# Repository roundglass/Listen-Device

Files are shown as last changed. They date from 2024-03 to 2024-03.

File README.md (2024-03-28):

# Roundglass Sustain Listen : Realtime Acoustic

## Monitoring

- **_Listen_**  is a modular acoustic station (device) and software / program to analyze sounds
- **_Listen_** is an end-end solution to collect sounds on the ground to infer intelligence
- **_Listen_** differs from other acoustic stations available in the market in its ease-of-use,
    set-up and portability
- It relies on solar-power, long-lasting battery and a plug-n-play communication system
    that would transmit data real-time to a console or App or Web interface.
- The data will be available real-time on smartphone/tablet through an application and
    would enable users to make informed decisions. Potential users are conservation and
    law enforcement personnel (forest department primarily) and NGOs and local
    communities who are interested in conserving their natural heritage.
- The app has capabilities to view data as graphs and in other forms of visualization. (Ex:
    used to observe trend of data over a requested time period like the sound
    characteristics.

## How does  Listen  work?

### Listen: working illustration

Listen isolates ‘sounds-of-interest’ from the surrounding or ambient sound. Sounds-of-interest
can be defined according to our needs - gunshots, dynamite blasts, motor vehicles, timber
felling, etc. The unit(Listen Mote) is installed in field and designed to blend in with the
surroundings - hidden in the tree canopy, etc. This can stay deployed for at least 4 weeks
without a battery change. There exists an option to connect it to a solar charger for longer
deployments. 

High-sensitivity microphones coupled with a data transmission system form the
field unit (Listen Mote). Information is received at a base station over cellular network.
The audio recording based on the programmed recording frequency is uploaded to our cloud
database which is linked to our cloud based virtual analytics system, once the system
determines that a particular recording is of interest (anomaly in the environment) then an alert is
sent out to the respective authority.

We foresee a need for these devices in the coming years owing to increased awareness
regarding conservation issues and also due to severe shortage of enforcement and patrol
personnel guarding our protected areas.

## Hardware 

### Roundglass Sustain Listen: components

**Microphones** : A high sensitivity microphone is used that will work for far field listening and has
digital gain to isolate noise amplification as in analog signal amplification.

**Form factor:**  Easy to conceal, hard shell polycarbonate, rounded edges, matte finish, no
external wiring or protruding antenna.

**Power source:** Solar powered with alternate power input for seasons and places with no
adequate solar radiation.

**Battery** : Li-ion pack can stay powered and deployed in field for at least 4 weeks without charge.

**Communication** : Wireless (GSM)

**Data** : App and Web based monitoring, configurable frequency and format of logging and
transmission.

**Switches** : Waterproof, dust-proof and insect-proof. No external switches.

**Mounting** : Compact system can be mounted on a mast or tripod of your choice.

## Technical Specifications

**Communication** : Global GSM

**Temperature** : -20 to 60 C

**Weatherproof** : IP 66/

**Battery:**  Rechargeable Li-ion battery.

**Solar Panel:**  Optional

**Alternate Power source** : Can plug a 6-12V external DC power supply (Optional)

**Application:** Android and iOS

## Applications

Protected areas are often vast, remote, with difficult terrain and severely understaffed to
effectively monitor and protect. With Roundglass Sustain Listen, we hope to plug in some of these gaps to
effectively monitor large areas and identify threats.

1. Detection of gunshots in protected areas - poaching and hunting increasingly rely on
    guns and is one of the leading causes of wildlife decline
2. Detection of dynamite fishing along rivers - illegal and highly destructive. The
    conservation and livelihood impacts of dynamite fishing is enormous
3. Detection of vehicular movement in protected areas - motor vehicles are used to illegally
    access areas for poaching, hunting and timber smuggling.
4. Another potential application (which we hope to address at a later date) is detection of
    wildfires

## Highlights:

1. Detects, locates and alerts on threat sounds in less than 60 seconds.

2. Simple, affordable subscription service — no IT integration required

3. Get notified on your existing mobile phone via SMS / App notification.

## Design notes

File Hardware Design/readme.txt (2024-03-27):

#Hardware Design

Schematics and PCB Design

Platform Eagle

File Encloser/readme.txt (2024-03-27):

#Encloser

STL and G code

Platform: Fusion 360 for Designing
	  PrusaSlicer for G Code

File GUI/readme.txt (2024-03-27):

#GUI

GUI V0.4

Steps to convert .py to .exe

1. Open cmd window and type 'pip install pyinstaller'
2. Open where python File is located in our case go inside Source folder
3. Press Shift and Right click at the Same location.
4. Click on ‘Open PowerShell window here’. 
5. Now type pyinstaller --listenConfig -w 'ListenConfig.py'

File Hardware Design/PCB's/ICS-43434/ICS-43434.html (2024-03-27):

Partlist exported from C:/Users/AdityaGarg/OneDrive - RoundGlass/Documents/EAGLE/projects/ICS-43434/ICS-43434.sch at 8/22/2023 10:27 AM

Part | Value | Device | Package | Description
C1 | 100nf | CC0805KRX7R9BB104 | CAP_0805 | CAP CER 0.1UF 50V X7R 0805
GND | | PINHD-1X1CB | 1X01-CLEANBIG | Pin header 1x1 for 0.1" spacing
IC1 | ICS-43434 | ICS-43434 | ICS43434 | MEMS Microphones (Microphone), SNR(Nom)=65dBA, LxWxT (mm)=3.5x2.65x0.98
LR | | PINHD-1X1CB | 1X01-CLEANBIG | Pin header 1x1 for 0.1" spacing
R1 | 100k | R-US_R0805 | R0805 | RESISTOR, American symbol
SCK | | PINHD-1X1CB | 1X01-CLEANBIG | Pin header 1x1 for 0.1" spacing
SD | | PINHD-1X1CB | 1X01-CLEANBIG | Pin header 1x1 for 0.1" spacing
VDD | | PINHD-1X1CB | 1X01-CLEANBIG | Pin header 1x1 for 0.1" spacing
WS | | PINHD-1X1CB | 1X01-CLEANBIG | Pin header 1x1 for 0.1" spacing

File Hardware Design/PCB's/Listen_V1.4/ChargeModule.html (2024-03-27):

Partlist exported from C:/Users/AdityaGarg/OneDrive - RoundGlass/Documents/EAGLE/projects/Listen_V1.4/ChargeModule.sch at 9/4/2023 12:24 PM

Qty | Value | Device | Package | Parts | Description | AVAILABILITY | DESCRIPTION | MARK | MF | MP | MPN | PACKAGE | POPULARITY | PRICE | PROD_ID | PURCHASE-URL | SPICEPREFIX
2 | | PINHD-1X6JSTXH | JST-XH-06-PACKAGE-ROUND-PAD | JP1, JP2 | PIN HEADER
1 | | USB_MICRO-B_FEMALE-SMT | USB-B-MICRO-SMD | J1 | USB Type Micro-B Connector | | | | | | | | | | CONN-11752
1 | 0 | R-US_M0805 | M0805 | R5 | RESISTOR, American symbol
1 | 0.1uf | RC-MASTER-SMD_C_0805MP | RC-MASTER-SMD_C0805MP | C7 | NON-POLARIZED CAP
1 | 1.0uH | L-USWE-TPC | POWER-CHOKE_WE-TPC | L1 | INDUCTOR, American symbol | | | | | | | | 0 | | | | L
1 | 100 | R-EU_R0805 | R0805 | R42 | RESISTOR, European symbol
1 | 100k | R-US_M0805 | M0805 | R3 | RESISTOR, American symbol
2 | 10k | R-US_M0805 | M0805 | R6, R7 | RESISTOR, American symbol
3 | 10uF | RC-MASTER-SMD_C_0805MP | RC-MASTER-SMD_C0805MP | C2, C3, C8 | NON-POLARIZED CAP
1 | 1K | R-EU_R0805 | R0805 | R43 | RESISTOR, European symbol
1 | 1k | R-US_M0805 | M0805 | R2 | RESISTOR, American symbol
1 | 1uF | RC-MASTER-SMD_C_0805MP | RC-MASTER-SMD_C0805MP | C1 | NON-POLARIZED CAP
2 | 22uF | RC-MASTER-SMD_C_0805MP | RC-MASTER-SMD_C0805MP | C5, C6 | NON-POLARIZED CAP
1 | 2k | R-US_M0805 | M0805 | R1 | RESISTOR, American symbol
1 | 47nF | RC-MASTER-SMD_C_0805MP | RC-MASTER-SMD_C0805MP | C4 | NON-POLARIZED CAP
2 | BK-18650-PC4 | BK-18650-PC4 | BAT_BK-18650-PC4 | BT1, BT2 | Battery Holder (Open) 18650 2 Cell PC Pin Check availability | In Stock | Battery Holder (Open) 18650 2 Cell PC Pin | | MPD | BK-18650-PC4 | | None | | None | | https://pricing.snapeda.com/search/part/BK-18650-PC4/?ref=eda
1 | DW01A | DW01A | SOT23-6 | IC3 | Check availability | Not in stock | One Cell Lithium-ion/Polymer Battery Protection IC | | Fortune Semiconductor | DW01A | | SOT-23-6 Fortune Semiconductor | | None
1 | FS8205 | FS8205 | SOT95P280X145-6N | Q2 | Dual N Channel Enhancement Mode Power MOSFET Check availability | Not in stock | Dual N-Channel Enhancement Mode Power MOSFET | | Fortune Semiconductor | FS8205 | | Package | | None
2 | JST-XH-02-PIN-ROUND-PAD | JST-XH-02-PIN-ROUND-PAD | JST-XH-02-PACKAGE-ROUND-PAD | X1, X2 | JST XH Connector 2 Pin
1 | MP2731GQC | MP2731GQC | QFN-26-3.5 | IC1 | | | | BMA__ | Monolithic Power | | MP2731GQC-0000-Z

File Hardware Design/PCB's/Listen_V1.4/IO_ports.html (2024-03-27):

Partlist exported from C:/Users/AdityaGarg/OneDrive - RoundGlass/Documents/EAGLE/projects/Listen_V1.4/IO_ports.sch at 8/22/2023 10:24 AM

Part | Value | Device | Package | Description
J6 | USB3131-30-0230-A | USB3131-30-0230-A | USB3131300230A | GCT (GLOBAL CONNECTOR TECHNOLOGY) - USB3131-30-0230-A - MICRO USB, 2.0 TYPE B, RECEPTACLE, THT
JP1 | | PINHD-1X6JSTXH | JST-XH-06-PACKAGE-ROUND-PAD | PIN HEADER
JP2 | | PINHD-1X6JSTXH | JST-XH-06-PACKAGE-ROUND-PAD | PIN HEADER
LED1 | | LEDCHIP-LED0805 | CHIP-LED0805 | LED
LED2 | | LEDCHIP-LED0805 | CHIP-LED0805 | LED
R1 | 2k | R-US_M0805 | M0805 | RESISTOR, American symbol
R4 | 2k | R-US_M0805 | M0805 | RESISTOR, American symbol
R7 | 1k | R-US_CHIP-0805(2012-METRIC) | RESC2012X65 | Resistor Fixed - ANSI
S1 | switch | MOMENTARY-SWITCH-SPST-PTH-6.0MM | TACTILE_SWITCH_PTH_6.0MM | Momentary Switch (Pushbutton) - SPST
S2 | Power Switch | MSS-102545-28A-D | SW_MSS-102545-28A-D | Check availability
X1 | JST-XH-02-PIN-LONG-PAD | JST-XH-02-PIN-LONG-PAD | JST-XH-02-PACKAGE-LONG-PAD | JST XH Connector 2 Pin
X2 | JST-XH-02-PIN-LONG-PAD | JST-XH-02-PIN-LONG-PAD | JST-XH-02-PACKAGE-LONG-PAD | JST XH Connector 2 Pin
X3 | JST-XH-03-PIN-LONG-PAD | JST-XH-03-PIN-LONG-PAD | JST-XH-03-PACKAGE-LONG-PAD | JST XH Connector 2 Pin
X4 | JST-XH-03-PIN-LONG-PAD | JST-XH-03-PIN-LONG-PAD | JST-XH-03-PACKAGE-LONG-PAD | JST XH Connector 2 Pin

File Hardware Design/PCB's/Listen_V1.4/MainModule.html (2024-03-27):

Partlist exported from C:/Users/AdityaGarg/OneDrive - RoundGlass/Documents/EAGLE/projects/Listen_V1.4/MainModule.sch at 8/22/2023 10:25 AM

Part | Value | Device | Package | Description
BME280 | | PINHD-1X6JSTXH | JST-XH-06-PACKAGE-ROUND-PAD | PIN HEADER
LEFT | | PINHD-1X6JSTXH | JST-XH-06-PACKAGE-ROUND-PAD | PIN HEADER
MODEM | | PINHD-1X6JSTXH | JST-XH-06-PACKAGE-ROUND-PAD | PIN HEADER
POWER | | PINHD-1X6JSTXH | JST-XH-06-PACKAGE-ROUND-PAD | PIN HEADER
R1 | 22k | R-US_CHIP-0805(2012-METRIC) | RESC2012X65 | Resistor Fixed - ANSI
R2 | 22k | R-US_CHIP-0805(2012-METRIC) | RESC2012X65 | Resistor Fixed - ANSI
RIGHT | | PINHD-1X6JSTXH | JST-XH-06-PACKAGE-ROUND-PAD | PIN HEADER
U$1 | 4GMODULE4GMODULE | 4GMODULE4GMODULE | 4GMODULE
U$2 | GPSANTENA | GPSANTENA | GPSANTENA
U1 | DEV-16771 | DEV-16771 | MODULE_DEV-16771 | RT1062 Teensy 4.1 i.MX ARM Cortex-M7 MPU Embedded Evaluation Board Check availability
U2 | 1053 | 1053 | 1053 | Coin Cell Battery Holders BATTERY HOLDER FOR CR2450
X1 | SOIL | JST-XH-02-PIN-LONG-PAD | JST-XH-02-PACKAGE-LONG-PAD | JST XH Connector 2 Pin

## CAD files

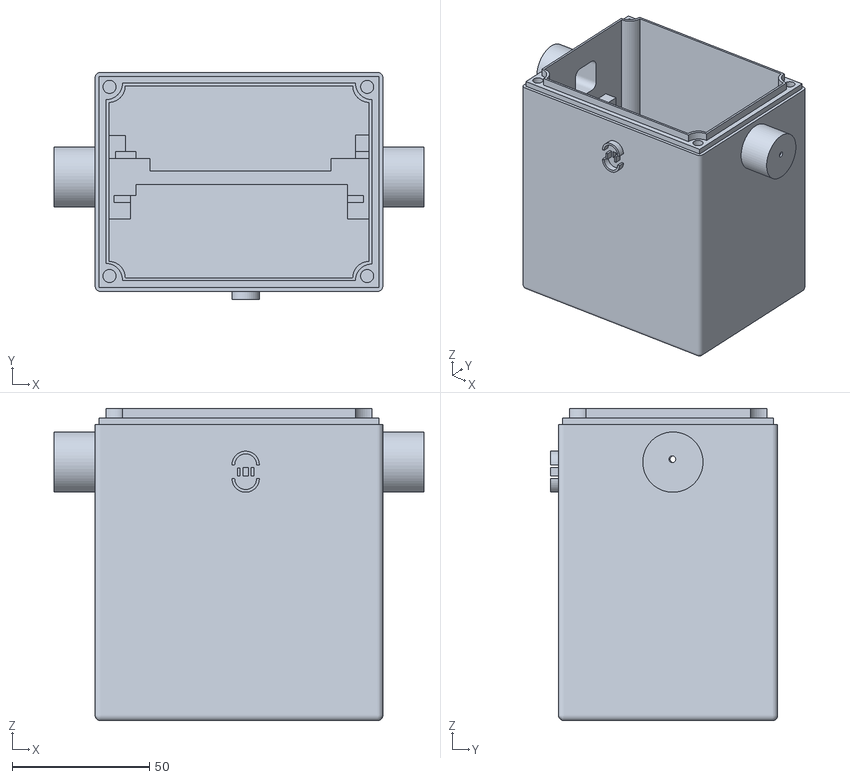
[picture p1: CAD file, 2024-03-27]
Encloser/STL/Encloser ListenV1.4 Base (In MIC).stl
135.0 x 83.0 x 114.0

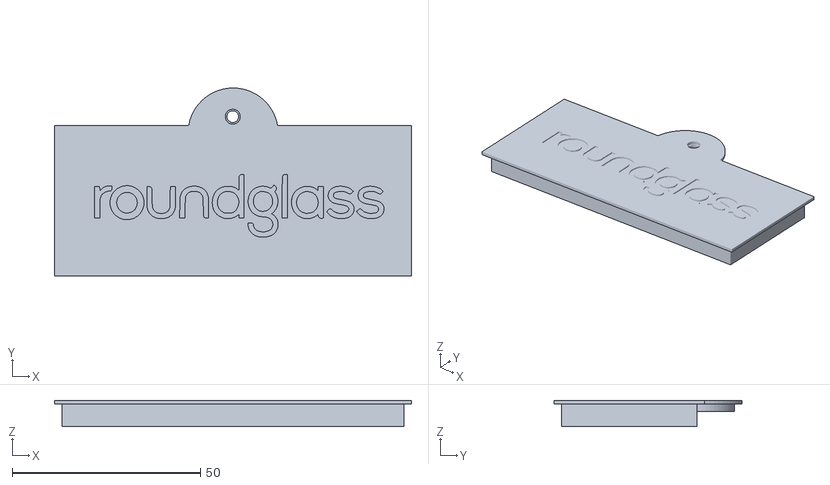
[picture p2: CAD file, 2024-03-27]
Encloser/STL/Encloser ListenV1.4 IOPort.stl
94.9 x 50.0 x 7.00

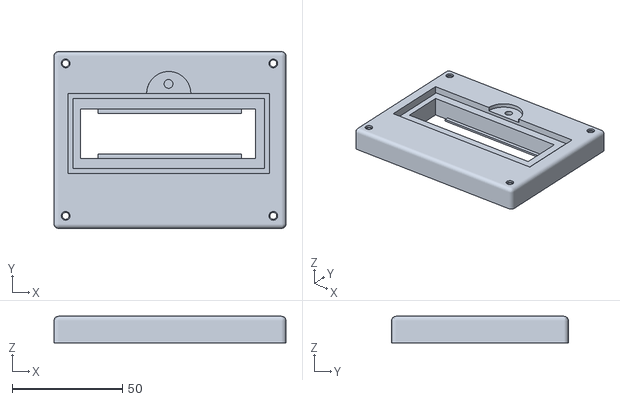
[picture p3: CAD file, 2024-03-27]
Encloser/STL/Encloser ListenV1.4 TOP.stl
105.0 x 80.0 x 12.0

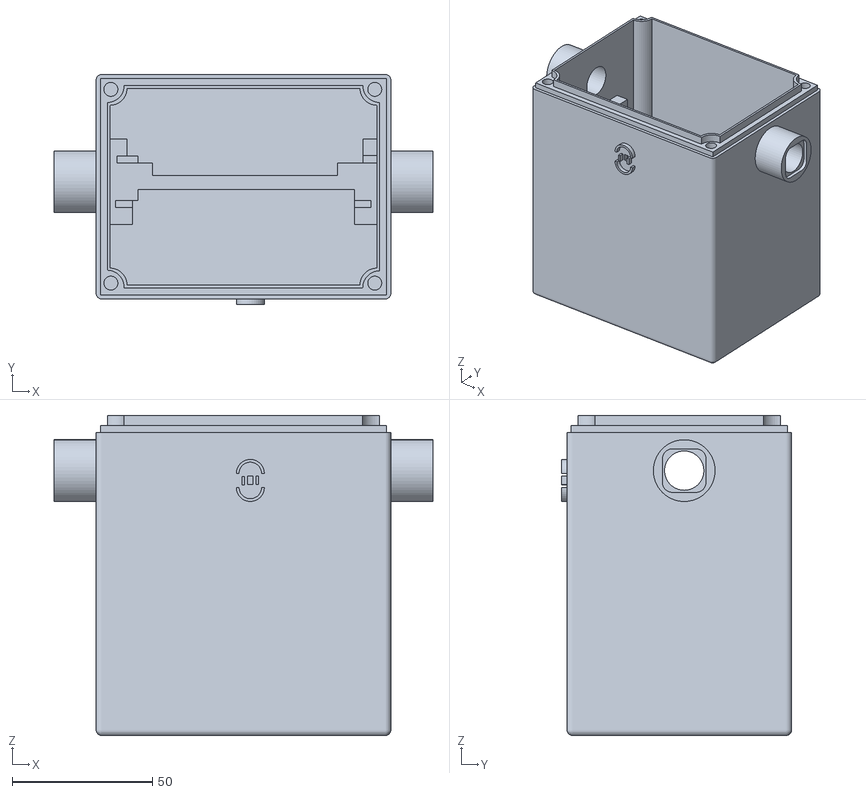
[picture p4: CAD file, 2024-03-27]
Encloser/STL/Encloser ListenV1.4 Base.stl
135.0 x 82.0 x 114.0

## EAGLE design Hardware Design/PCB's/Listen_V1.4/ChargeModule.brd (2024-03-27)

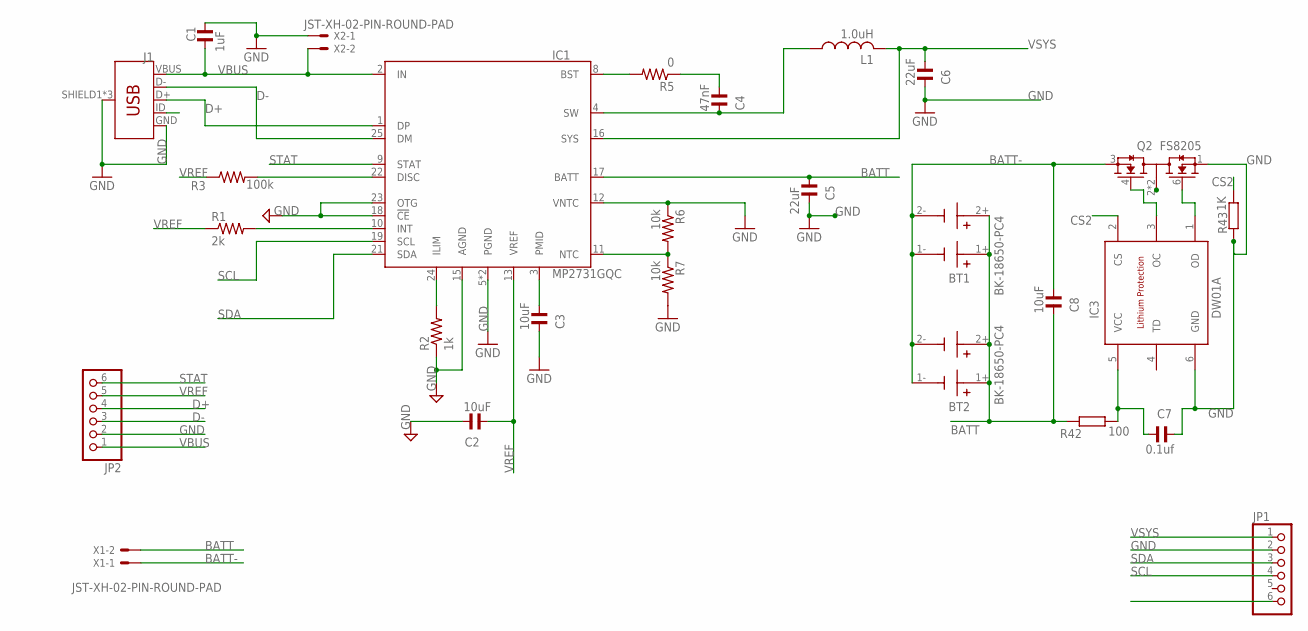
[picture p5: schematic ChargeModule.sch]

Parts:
BT1, BT2: BK-18650-PC4; BAT_BK-18650-PC4
C1: 1uF; RC-MASTER-SMD_C0805MP
C2, C3, C8: 10uF; RC-MASTER-SMD_C0805MP
C4: 47nF; RC-MASTER-SMD_C0805MP
C5, C6: 22uF; RC-MASTER-SMD_C0805MP
C7: 0.1uf; RC-MASTER-SMD_C0805MP
IC1: MP2731GQC; QFN-26-3.5
IC3: DW01A; SOT23-6
J1: USB_MICRO-B_FEMALE-SMT; USB-B-MICRO-SMD
JP1, JP2: PINHD-1X6JSTXH; JST-XH-06-PACKAGE-ROUND-PAD
L1: 1.0uH; POWER-CHOKE_WE-TPC
Q2: FS8205; SOT95P280X145-6N
R1: 2k; M0805
R2: 1k; M0805
R3: 100k; M0805
R5: 0; M0805
R6, R7: 10k; M0805
R42: 100; R0805
R43: 1K; R0805
X1, X2: JST-XH-02-PIN-ROUND-PAD; JST-XH-02-PACKAGE-ROUND-PAD

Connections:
BATT: BT1.1+, BT1.2+, BT2.1+, BT2.2+, C5.1, C8.2, IC1.17 (BATT), R42.2, X1.2
BATT-: BT1.1-, BT1.2-, BT2.1-, BT2.2-, C8.1, Q2.3 (S2), X1.1
CS2: IC3.2 (CS), R43.1
D+: IC1.1 (DP), J1.D+, JP2.4
D-: IC1.25 (DM), J1.D-, JP2.3
GND: C1.2, C2.2, C3.2, C5.2, C6.2, C7.2, IC1.5 (PGND), IC1.6 (PGND), IC1.12 (VNTC), IC1.15 (AGND), IC1.18 (!CE), IC1.23 (OTG), IC3.6 (GND), J1.GND, J1.SHIELD1 (SHIELD), J1.SHIELD2 (SHIELD), J1.SHIELD3 (SHIELD), JP1.2, JP2.2, Q2.1 (S1), R2.1, R6.1, R7.2, R43.2, X2.1
unnamed: IC1.24 (ILIM), R2.2
unnamed: IC1.10 (INT), R1.2
unnamed: IC1.22 (DISC), R3.2
unnamed: IC1.8 (BST), R5.2
unnamed: C3.1, IC1.3 (PMID)
unnamed: C4.1, R5.1
unnamed: C4.2, IC1.4 (SW), L1.1
unnamed: IC1.11 (NTC), R6.2, R7.1
unnamed: Q2.2 (D12), Q2.5 (D12)
unnamed: C7.1, IC3.5 (VCC), R42.1
unnamed: IC3.1 (OD), Q2.6 (G1)
unnamed: IC3.3 (OC), Q2.4 (G2)
SCL: IC1.19 (SCL), JP1.4
SDA: IC1.21 (SDA), JP1.3
STAT: IC1.9 (STAT), JP2.6
VBUS: C1.1, IC1.2 (IN), J1.VBUS, JP2.1, X2.2
VREF: C2.1, IC1.13 (VREF), JP2.5, R1.1, R3.1
VSYS: C6.1, IC1.16 (SYS), JP1.1, L1.2

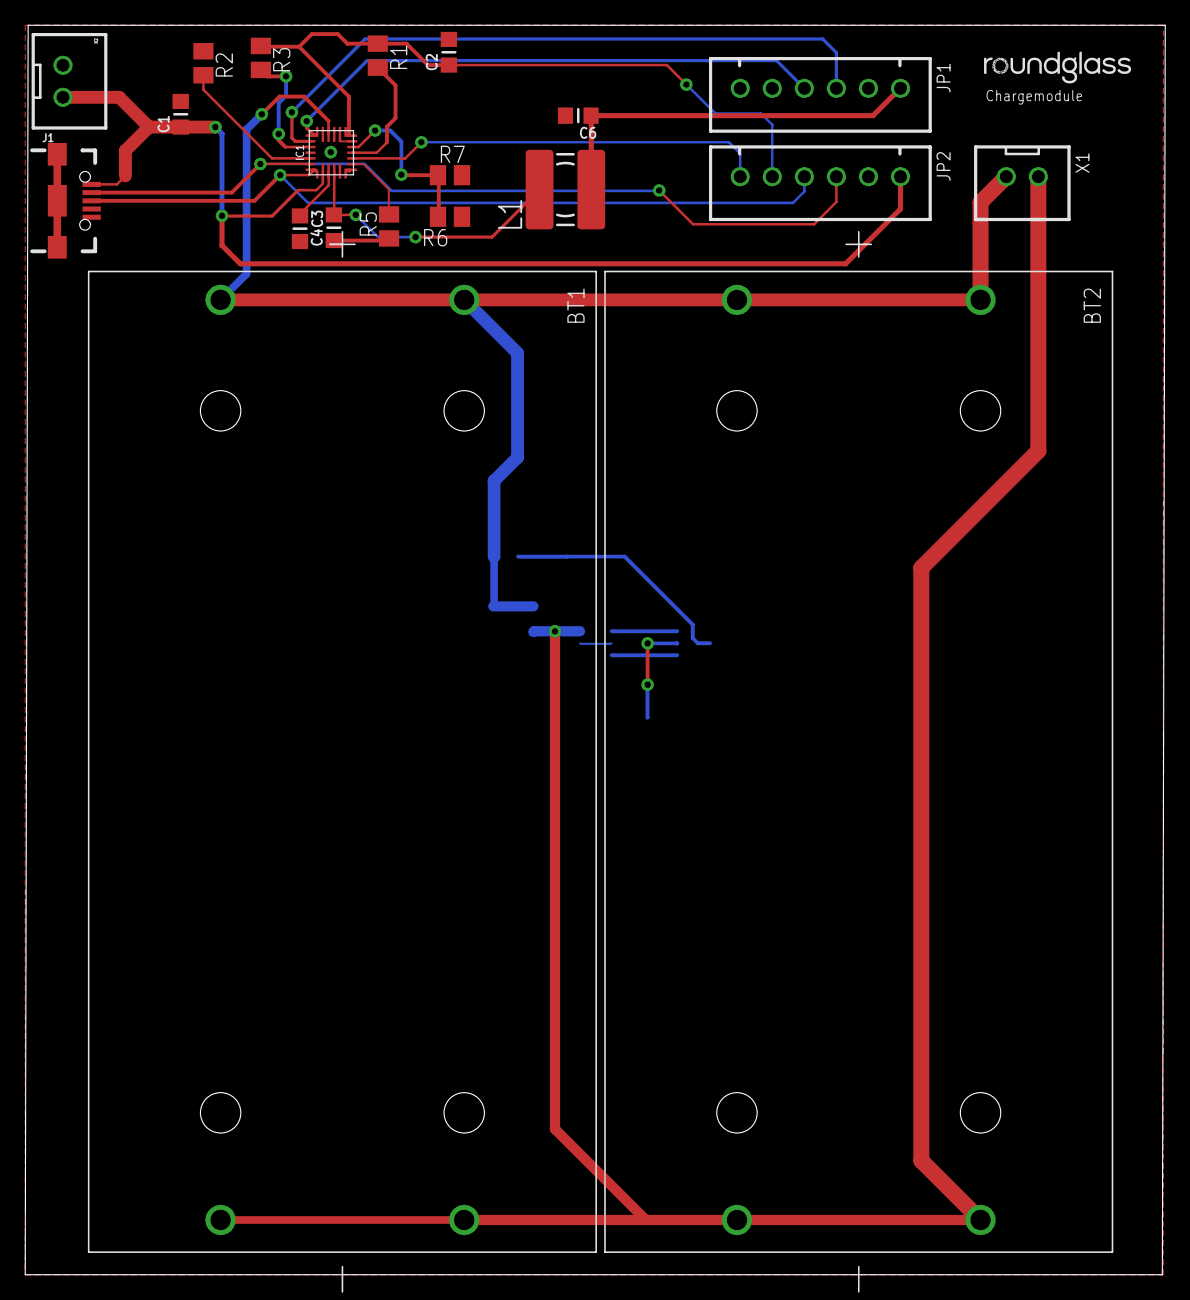
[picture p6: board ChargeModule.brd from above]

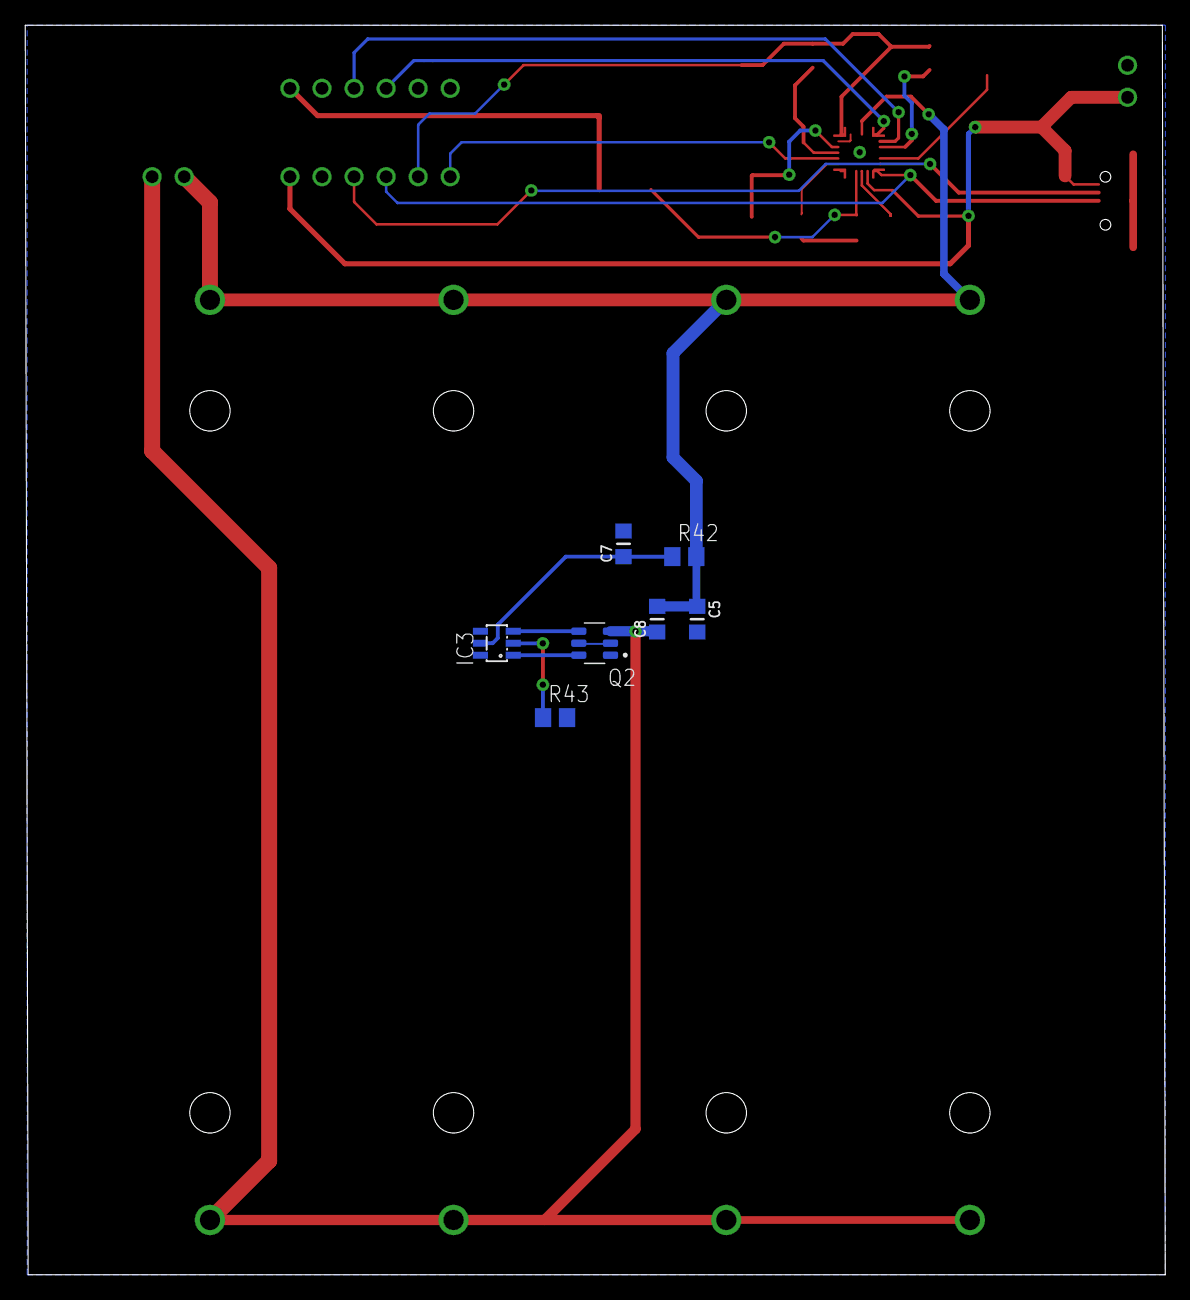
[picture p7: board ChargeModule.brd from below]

Board: 2 copper layers, 90.3 x 99.0 mm, 27 parts (7 on the bottom side), 24 nets.

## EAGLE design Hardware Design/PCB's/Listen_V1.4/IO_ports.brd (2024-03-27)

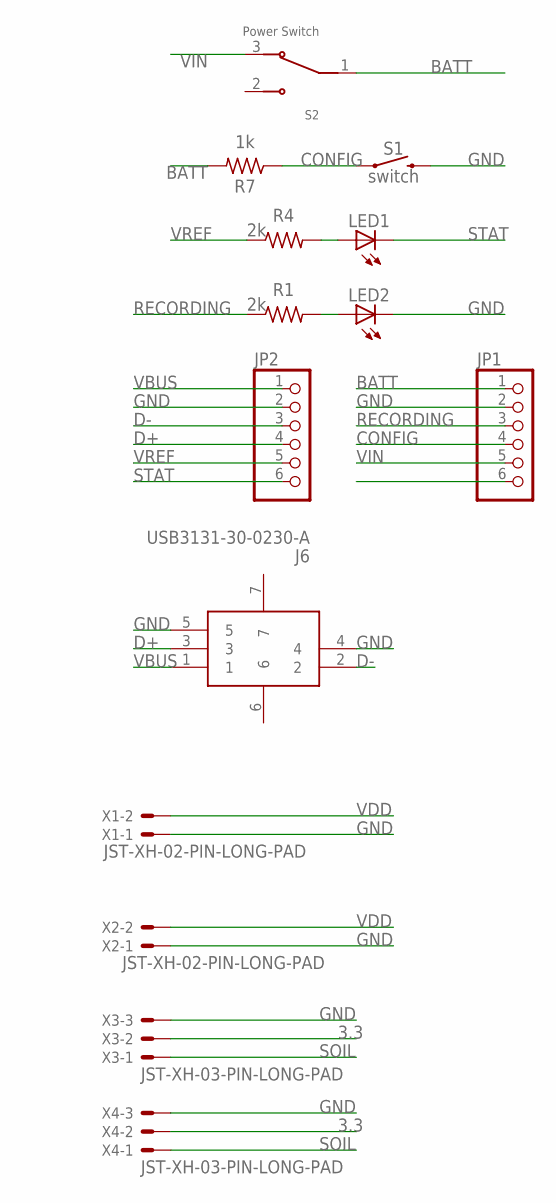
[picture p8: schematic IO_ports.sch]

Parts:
J6: USB3131-30-0230-A; USB3131300230A
JP1, JP2: PINHD-1X6JSTXH; JST-XH-06-PACKAGE-ROUND-PAD
LED1, LED2: LEDCHIP-LED0805; CHIP-LED0805
R1, R4: 2k; M0805
R7: 1k; RESC2012X65
S1: switch; TACTILE_SWITCH_PTH_6.0MM
S2: Power Switch; SW_MSS-102545-28A-D
X1, X2: JST-XH-02-PIN-LONG-PAD; JST-XH-02-PACKAGE-LONG-PAD
X3, X4: JST-XH-03-PIN-LONG-PAD; JST-XH-03-PACKAGE-LONG-PAD

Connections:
3.3: X3.2, X4.2
BATT: JP1.1, R7.2, S2.1
CONFIG: JP1.4, R7.1, S1.1
D+: J6.3, JP2.4
D-: J6.2, JP2.3
GND: J6.4, J6.5, JP1.2, JP2.2, LED2.C, S1.3 (2), X1.1, X2.1, X3.3, X4.3
unnamed: LED2.A, R1.2
unnamed: LED1.A, R4.2
RECORDING: JP1.3, R1.1
SOIL: X3.1, X4.1
STAT: JP2.6, LED1.C
VBUS: J6.1, JP2.1
VDD: X1.2, X2.2
VIN: JP1.5, S2.3
VREF: JP2.5, R4.1

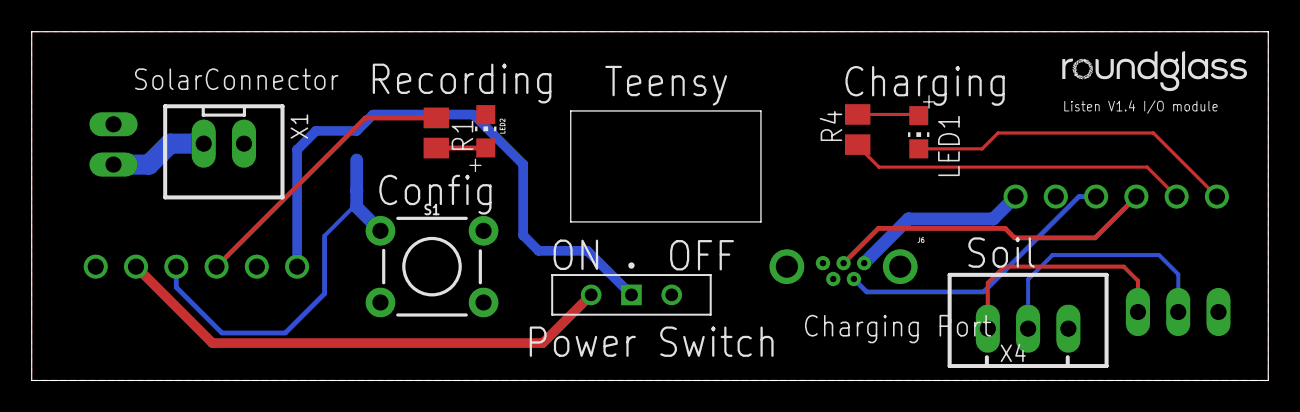
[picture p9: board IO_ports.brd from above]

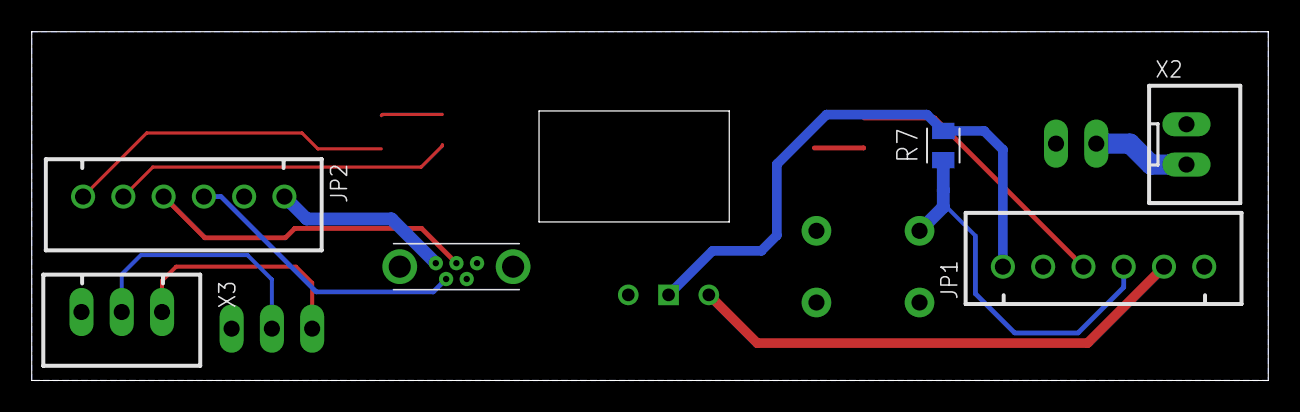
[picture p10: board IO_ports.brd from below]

Board: 2 copper layers, 78.0 x 22.0 mm, 14 parts (6 on the bottom side), 15 nets.

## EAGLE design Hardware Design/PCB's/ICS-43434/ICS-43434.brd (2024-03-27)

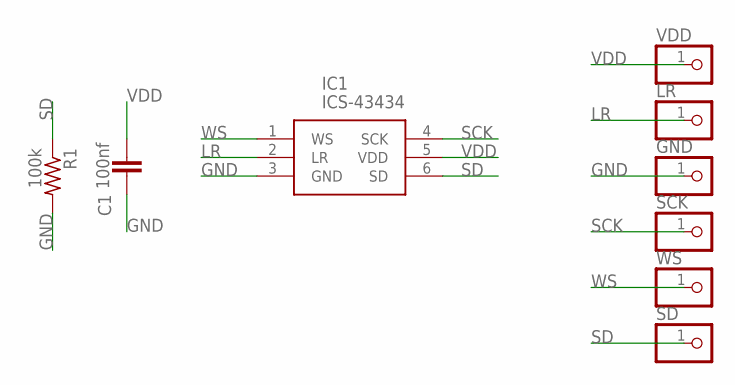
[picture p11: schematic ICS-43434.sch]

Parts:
C1: 100nf; CAP_0805
GND: PINHD-1X1CB; 1X01-CLEANBIG
IC1: ICS-43434; ICS43434
LR: PINHD-1X1CB; 1X01-CLEANBIG
R1: 100k; R0805
SCK: PINHD-1X1CB; 1X01-CLEANBIG
SD: PINHD-1X1CB; 1X01-CLEANBIG
VDD: PINHD-1X1CB; 1X01-CLEANBIG
WS: PINHD-1X1CB; 1X01-CLEANBIG

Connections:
GND: C1.1, GND.1, IC1.3 (GND), R1.2
LR: IC1.2 (LR), LR.1
SCK: IC1.4 (SCK), SCK.1
SD: IC1.6 (SD), R1.1, SD.1
VDD: C1.2, IC1.5 (VDD), VDD.1
WS: IC1.1 (WS), WS.1

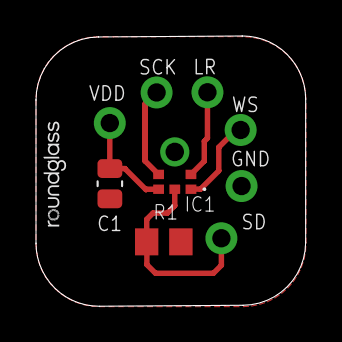
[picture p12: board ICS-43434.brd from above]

Board: 2 copper layers, 15.0 x 15.0 mm, 9 parts (0 on the bottom side), 6 nets.

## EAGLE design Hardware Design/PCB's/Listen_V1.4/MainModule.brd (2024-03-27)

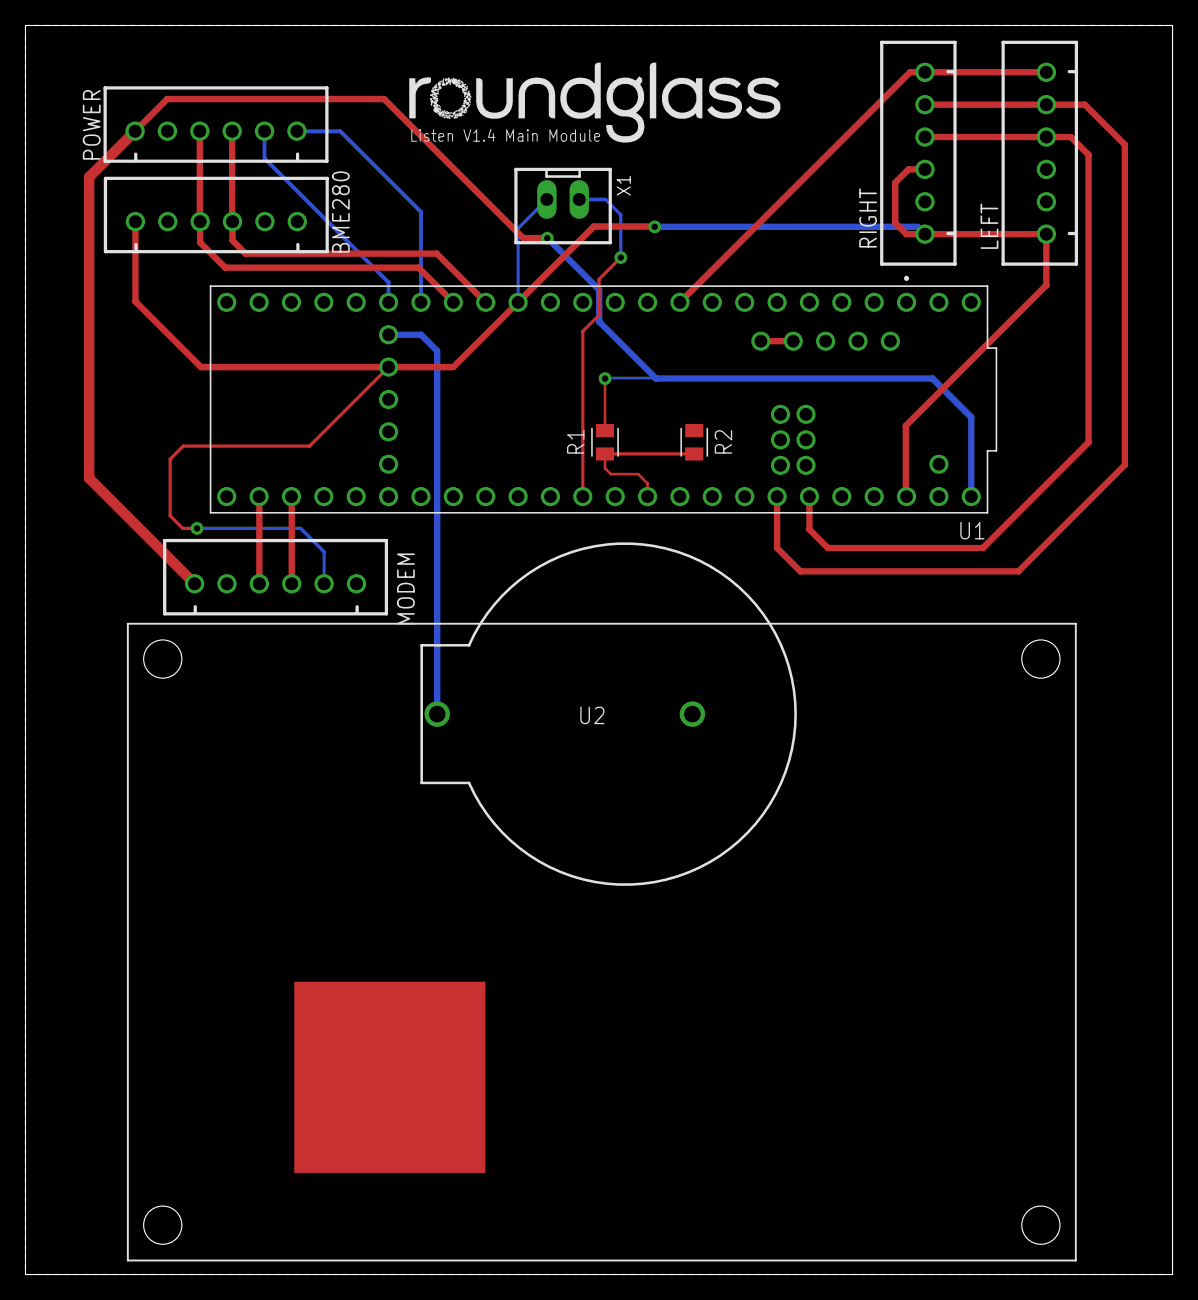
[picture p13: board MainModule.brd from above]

Board: 2 copper layers, 90.0 x 98.0 mm, 12 parts (0 on the bottom side), 16 nets.

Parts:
BME280: JST-XH-06-PACKAGE-ROUND-PAD
LEFT: JST-XH-06-PACKAGE-ROUND-PAD
MODEM: JST-XH-06-PACKAGE-ROUND-PAD
POWER: JST-XH-06-PACKAGE-ROUND-PAD
R1, R2: 22k; RESC2012X65
RIGHT: JST-XH-06-PACKAGE-ROUND-PAD
U1: DEV-16771; MODULE_DEV-16771
U2: 1053
U$1: 4GMODULE4GMODULE; 4GMODULE
U$2: GPSANTENA
X1: SOIL; JST-XH-02-PACKAGE-LONG-PAD

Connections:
3.3V: BME280.1, LEFT.1, MODEM.5, RIGHT.1, RIGHT.3, U1.3.3V_1, U1.3.3V_2, U1.3.3V_3, X1.2
CONFIG: POWER.5, U1.27
GND: BME280.2, LEFT.2, LEFT.3, MODEM.2, MODEM.6, POWER.2, R2.1, RIGHT.2, U1.GND1, U1.GND2, U1.GND3, U1.GND4, U1.GND5, U2.1
unnamed: R1.1, R2.2, U1.16
RECORDING: POWER.6, U1.26
RX: MODEM.3, U1.34
SCK: LEFT.4, RIGHT.4, U1.21
SCL: BME280.4, POWER.4, U1.24
SD: LEFT.6, RIGHT.6, U1.8
SDA: BME280.3, POWER.3, U1.25
SOIL: U1.14, X1.1
TX: MODEM.4, U1.35
USB_GND: U1.USB_GND1, U1.USB_GND2
VBAT: U1.VBAT, U2.2
VIN: MODEM.1, POWER.1, R1.2, U1.VIN
WS: LEFT.5, RIGHT.5, U1.20

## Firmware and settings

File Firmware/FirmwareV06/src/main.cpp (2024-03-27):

#include <Arduino.h>
#include <TeensyThreads.h>
#include <utility/imxrt_hw.h>
#include <TimeLib.h>
#include <TimeAlarms.h>
#include <Audio.h>
#include <SD.h>
#include <Metro.h>

#include <bme680.h>
#include <sdcard.h>
#include <MP2731.h>
#include <ftpQueue.h>
#include "recAudio.h"
#include <param.h>

#include <SoftwareSerial.h>
#include "DEV_Config.h"
#include "L76X.h"
GNRMC GPS1;



//====================================//Flags are here//==========================================//
bool _recording = false;
bool locTime = false;
bool ftpConn = false;

//---------------------------------//Variable are here//-----------------------------------------//
volatile int id_bme;
volatile int id_interrupt;
volatile int id_record; 
volatile int id_ftptransfer;

int count = 0;
int micmode = 1;
int interrupts = 9;
int envCount = 0;
RecordConfig RC1;

//----------------------------------//Record Variable//--------------//
unsigned long ChunkSize = 0L;
unsigned long Subchunk1Size = 16;
unsigned int AudioFormat = 1;
unsigned int numChannels = 2;
unsigned long sampleRate = 48000;
unsigned int bitsPerSample = 16;
unsigned long byteRate = sampleRate * numChannels * (bitsPerSample / 8); // samplerate x channels x (bitspersample / 8)
unsigned int blockAlign = numChannels * bitsPerSample / 8;
unsigned long Subchunk2Size = 0L;
unsigned long recByteSaved = 0L;
unsigned long NumSamples = 0L;
byte byte1, byte2, byte3, byte4;

const int myInput = AUDIO_INPUT_MIC;

//----------------------filename-------------------------//
File recordFile;
char deviceID[15] = {'\0'};
char fileName[150] = {'\0'};


//----------------------------------------//Mutex defined here//-----------------------------------------//
Threads::Mutex configlock;
Threads::Mutex bmeLock;
Threads::Mutex recordlock;

//--------------------------------//Class objects//---------------------------------------------//
bme680 BME;
sdcard sd;
ftpQueue fileQueue;
Metro recordduration = Metro(10000);

//-------------------------------//function declaration//---------------------------------------//
time_t getTeensy3Time()
{ // Function for Teensy sync provider
  return Teensy3Clock.get();
}
void setGain(){   //-----------------------------Set Gain----------------------------------//
  if (RC1.Gain == "Low")
  {
    amp1.gain(10);
    amp2.gain(10);
  }
  else if (RC1.Gain == "Medium")
  {
    amp1.gain(15);
    amp2.gain(15);
  }
  else if (RC1.Gain == "High")
  {
    amp1.gain(20);
    amp2.gain(20);
  }
  else
  {
    amp1.gain(15);
    amp2.gain(15);
  }
  Serial.print("Gain Configured!\n\r");
}
void record();
void stop();
void writeOutheader();
void env();          // Env Data function
void Locationtime(); // Location and time function for Quectel
void getData();      // interrupt thread
void setI2SFreq(int);
void setTime(String);
void ftpConnect();
void appendRecord();
void appendEnv(String FileName);
void ftptransfer();
void stackCheck();
void softReset(){
  SCB_AIRCR = 0x05FA0004;
}
void recstart()
{ // function to add threads
  threads.addThread(record, 0, 4096);
}
void printtime(){
  Serial.print(year());
  Serial.print("-");
  Serial.print(month());
  Serial.print("-");
  Serial.print(day());
  Serial.print(" ");
  Serial.print(hour());
  Serial.print(":");
  if (minute() < 10)
      Serial.print('0');
  Serial.print(minute());
  Serial.print(":");
  if (second() < 10)
      Serial.print('0');
  Serial.print(second());
  Serial.print("\n\r");
}

//-------------------------------//Setup function//---------------------------------------------//
void setup(){ 
  
  pinMode(34, INPUT);
  pinMode(35, OUTPUT);
  
  mySerial.begin(9600); 

  mySerial.println("Hello World - SoftwareSerial");

  DEV_Set_Baudrate(9600);
  DEV_Delay_ms(500);

  /*
  Serial.begin(115200);
  Serial.print("//---------------------------Listen V1.4---------------------------------//\n\r");

  // GPIO SETUP
  setSyncProvider(getTeensy3Time);
  pinMode(interrupts, INPUT);
  pinMode(LED_BUILTIN, OUTPUT);

  digitalWrite(LED_BUILTIN, HIGH);
  delay(2000);
  digitalWrite(LED_BUILTIN, LOW);

  AudioMemory(400);

  biquad1.setHighpass(0, 200, 0.707);
  biquad2.setHighpass(0, 200, 0.707);
  
  sd.init();
  sd.createConfigFile();
  RC1 = sd.loadConfig();

  while (RC1.DeviceID == "")
  {
    digitalWrite(LED_BUILTIN, HIGH);
    delay(200);
    digitalWrite(LED_BUILTIN, LOW);
    delay(200);
    Serial.print("NO DATA FOUND!!!!!\n");
  }

  setGain();
  setI2SFreq(48000);

  threads.addThread(stackCheck); //Function for Checking Stack Usage
  threads.addThread(getData);
  threads.addThread(env, 0, 2048);
  //threads.addThread(Locationtime);




  if(RC1.uploadcheck == "True"){
    Serial8.begin(921600);
    ftpConnect();
    threads.addThread(ftptransfer,0,2048);
  }


  if (RC1.micMode == "Mono L")
  {
    micmode = 2;
    numChannels = 1;
  }
  else if (RC1.micMode == "Mono R")
  {
    micmode = 3;
    numChannels = 1;
  }
  else
  {
    micmode = 1;
    numChannels = 2;
  }
  Serial.print("Microphone mode Configured!\n\r");

  //while(locTime==false){ } //This comment is to be removed

  if (RC1.RecordMode == "Interval Mode")
  {

    if (RC1.Count1.toInt() > 0)
    {
      for (int i = 0; i < RC1.Count1.toInt(); i++)
      {
        Alarm.alarmRepeat(RC1.StartDuration[i].toInt() / 100, RC1.StartDuration[i].toInt() % 100, 0, recstart);
        Alarm.alarmRepeat(RC1.EndDuration[i].toInt() / 100, RC1.EndDuration[i].toInt() % 100, 0, stop);
      }
    }
    else
    {
      while (!(second() % 10 == 0))
      {
      }
      recstart();
    }
  }
  else
  {
    while (!(second() % 10 == 0))
    {
    }
    recstart();
  }
  Serial.print("Mode Configured!\n\r");
  Serial.print("Setup Complete\n\r");
*/

}

void loop()
{
  Alarm.delay(0);
  GPS1 = L76X_Gat_GNRMC();
  Serial.print("\r\n");
  Serial.print("Time:");
  Serial.print(GPS1.Time_H);
  Serial.print(":");
  Serial.print(GPS1.Time_M); 
  Serial.print(":");
  Serial.print(GPS1.Time_S);
  Serial.print("\r\n");
}

//-----------------------------------//Envdata function//--------------------------------------//
void env()
{
  id_bme = threads.id();

  while (1)
  {
    threads.delay(60 * 1000);
    Threads::Scope bme(bmeLock);
    BME.saveEnv(envCount);
    BME.printData();
    count++;
    if (count == 60)
    {
      appendEnv(BME.getfileName());
      count = 0;
      envCount++;
    }
  }
}

//-----------------------------------//Loaction and time//------------------------------------//
void Locationtime(){
  String r;
  Serial8.begin(115200);

  Serial.print("AT\n\r");
  Serial8.print("AT\r\n");
  while (!Serial8.available())
  {
  }
  r = Serial8.readString();
  Serial.print(r);
  threads.delay(1000);

  Serial.print("ATE0\n\r");
  Serial8.print("ATE0\r\n");
  while (!Serial8.available())
  {
  }
  r = Serial8.readString();
  Serial.print(r);
  threads.delay(1000);

  Serial.print("AT+IPR=921600\n\r");
  Serial8.print("AT+IPR=921600\r\n");
  while (!Serial8.available())
  {
  }
  r = Serial8.readString();
  Serial.print(r);
  Serial8.begin(921600);
  threads.delay(1000);

  Serial.print("AT+IPR?\n\r");
  Serial8.print("AT+IPR?\r\n");
  while (!Serial8.available())
  {
  }
  r = Serial8.readString();
  Serial.print(r);
  threads.delay(1000);

  Serial.print("AT+QGPS?\n\r");
  Serial8.print("AT+QGPS?\r\n");
  while (!Serial8.available())
  {
  }
  r = Serial8.readString();
  Serial.print(r);
  threads.delay(1000);

  if (r == "\r\n+QGPS: 1\r\n\r\nOK\r\n")
  {
    Serial.print("AT+QGPSLOC?\n\r");
    Serial8.print("AT+QGPSLOC?\r\n");
    while (!Serial8.available())
    {
    }
    r = Serial8.readString();
    Serial.print(r);
  }
  else
  {
    Serial.print("AT+QGPS=1\n\r");
    Serial8.print("AT+QGPS=1\r\n");
    while (!Serial8.available())
    {
    }
    r = Serial8.readString();
    Serial.print(r);
    threads.delay(1000);

    Serial.print("AT+QGPSLOC?\n\r");
    Serial8.print("AT+QGPSLOC?\r\n");
    while (!Serial8.available())
    {
    }
    r = Serial8.readString();
    Serial.print(r);
    threads.delay(1000);
  }

  while (r == "\r\n+CME ERROR: 516\r\n")
  {
    threads.delay(35000);
    Serial.print("AT+QGPSLOC?\n\r");
    Serial8.print("AT+QGPSLOC?\r\n");
    while (!Serial8.available())
    {
    }
    r = Serial8.readString();
    Serial.print(r);
  }
  setTime(r);
  locTime = true;
}

//----------------------------------//Interuupt thread function//-----------------------------------//
void getData(){

  id_interrupt = threads.id();

  while (1)
  {
    if (digitalRead(interrupts) == LOW)
    {
      Serial.print("In configuration mode\n\r");

      while (!Serial.available())
      {
        digitalWrite(LED_BUILTIN, HIGH);
        delay(500);
        digitalWrite(LED_BUILTIN, LOW);
        delay(500);
      }

      sd.getConfig();
      Serial.print("exiting Confuguration Mode");
      softReset();
    }
    threads.delay(10000);
  }
}

//----------------------------------//Set sample Rate//--------------------------------------------------//
void setI2SFreq(int freq){
  // PLL between 27*24 = 648MHz und 54*24=1296MHz
  int n1 = 4; // SAI prescaler 4 => (n1*n2) = multiple of 4
  int n2 = 1 + (24000000 * 27) / (freq * 256 * n1);
  double C = ((double)freq * 256 * n1 * n2) / 24000000;
  int c0 = C;
  int c2 = 10000;
  int c1 = C * c2 - (c0 * c2);
  set_audioClock(c0, c1, c2, true);
  CCM_CS1CDR = (CCM_CS1CDR & ~(CCM_CS1CDR_SAI1_CLK_PRED_MASK | CCM_CS1CDR_SAI1_CLK_PODF_MASK)) | CCM_CS1CDR_SAI1_CLK_PRED(n1 - 1) // &0x07
               | CCM_CS1CDR_SAI1_CLK_PODF(n2 - 1);                                                                                // &0x3f
  Serial.printf("SetI2SFreq(%d)\n\r", freq);
}

//---------------------------------------------//Set Time//-----------------------------------------//
void setTime(String r){

  time_t time;
  int tim;
  int date;
  String t;
  String d;

  t = r.substring(12, 20);
  d = r.substring(69, 75);
  tim = t.toInt();
  date = d.toInt();
  int hour = tim / 10000;
  tim = tim % 10000;
  int minute = tim / 100;
  int second = tim % 100;

  int day = date / 10000;
  date = date % 10000;
  int month = date / 100;
  int year = date % 100;
  if (year > 99)
    year = year - 1970;
  else
    year += 30;

  time = makeTime(day, month, year, hour, minute, second);

  Teensy3Clock.set(time);
}

//------------------------------------------------------//Recordfunctions//-------------------------------------------//
void record()
{ // Record
  id_record = threads.id();
  while (1)
  {
    String r;
    snprintf(fileName, sizeof(fileName), "%s/record/%d%02d%02d_%02d%02d%02d_#%s.wav", RC1.DeviceID.c_str(),year(), month(), day(), hour(), minute(), second(), RC1.DeviceID.c_str());
    recordFile = SD.open(fileName, FILE_WRITE);
    if (recordFile)
    {
      queue1.begin();
      queue2.begin();
      recByteSaved = 0L;
    }
    recordduration.interval(RC1.RecordDuration.toInt() * 1000); // Record Duration;
    digitalWrite(LED_BUILTIN, HIGH);
    recordduration.reset();

    while (1)
    {
      if (recordduration.check() == 1)
      {
        recordlock.lock();
        Serial.print("Record Stop\n\r");
        appendRecord();
        queue1.end();
        queue2.end();
        if (recordFile)
        {
          while (queue1.available() > 0)
          {
            recordFile.write((byte *)queue1.readBuffer(), 256);
            recordFile.write((byte *)queue2.readBuffer(), 256);
            queue1.freeBuffer();
            queue2.freeBuffer();
            recByteSaved += 512;
          }
          writeOutheader();
          recordFile.close();
          digitalWrite(LED_BUILTIN, LOW);
          recordlock.unlock();
        }
        break;
        break;
      }
      else
      { 
        switch (micmode)
        {
        case '3':  
          if (queue1.available() >= 2) {
            recordlock.lock();
            byte *buffer = (byte *) malloc(512);
            memcpy(buffer, queue1.readBuffer(), 256);
            queue1.freeBuffer();
            memcpy(buffer + 256, queue1.readBuffer(), 256);
            queue1.freeBuffer();
            // write all 512 bytes to the SD card
            recordFile.write(buffer, 512);
            recByteSaved += 512;
            free(buffer);
            recordlock.unlock();
            }
          break;
        
        case '2':
          if (queue1.available() >= 2) {
            recordlock.lock();
            byte *buffer = (byte *) malloc(512);
            memcpy(buffer, queue2.readBuffer(), 256);
            queue1.freeBuffer();
            memcpy(buffer + 256, queue2.readBuffer(), 256);
            queue1.freeBuffer();
            // write all 512 bytes to the SD card
            Serial8.write(buffer,512);
            recordFile.write(buffer, 512);
            recByteSaved += 512;
            free(buffer);
            recordlock.unlock();
            }
          break;
        
        default:
        if (queue1.available() >= 2)
        {
          recordlock.lock();
          byte *buffer = (byte *) malloc(512);
          byte *bufferL = (byte *) malloc(256);
          byte *bufferR = (byte *) malloc(256);
          memcpy(bufferL, queue1.readBuffer(), 256);
          queue1.freeBuffer();
          memcpy(bufferR, queue2.readBuffer(), 256);
          queue2.freeBuffer();

          int b = 0;
          for (int i = 0; i < 512; i += 4)
          {
            buffer[i] = bufferL[b];
            buffer[i + 1] = bufferL[b + 1];
            buffer[i + 2] = bufferR[b];
            buffer[i + 3] = bufferR[b + 1];
            b = b + 2;
          }
          recordFile.write(buffer,512);
          Serial8.write(buffer,512);
          recByteSaved += 512;
          free(buffer);
          free(bufferL);
          free(bufferR);
          recordlock.unlock();
        }
          break;
        }
      }
    }
  
    threads.delay(RC1.SleepDuration.toInt()* 1000); // Sleep Duration;
  }
}

void stop()
{
  Serial.print("Record Stop\n\r");
  queue1.end();
  queue2.end();
  if (recordFile)
  {
    while (queue1.available() > 0)
    {
      recordFile.write((byte *)queue1.readBuffer(), 256);
      recordFile.write((byte *)queue2.readBuffer(), 256);
      queue1.freeBuffer();
      queue2.freeBuffer();
      recByteSaved += 512;
    }
    writeOutheader();
    recordFile.close();

    digitalWrite(LED_BUILTIN, LOW);
  }
}

void writeOutheader()
{ // Wav Header
  //  NumSamples = (recByteSaved*8)/bitsPerSample/numChannels;
  //  Subchunk2Size = NumSamples*numChannels*bitsPerSample/8; // number of samples x number of channels x number of bytes per sample
  Subchunk2Size = recByteSaved;
  ChunkSize = Subchunk2Size + 36;
  recordFile.seek(0);
  recordFile.write("RIFF");
  byte1 = ChunkSize & 0xff;
  byte2 = (ChunkSize >> 8) & 0xff;
  byte3 = (ChunkSize >> 16) & 0xff;
  byte4 = (ChunkSize >> 24) & 0xff;
  recordFile.write(byte1);
  recordFile.write(byte2);
  recordFile.write(byte3);
  recordFile.write(byte4);
  recordFile.write("WAVE");
  recordFile.write("fmt ");
  byte1 = Subchunk1Size & 0xff;
  byte2 = (Subchunk1Size >> 8) & 0xff;
  byte3 = (Subchunk1Size >> 16) & 0xff;
  byte4 = (Subchunk1Size >> 24) & 0xff;
  recordFile.write(byte1);
  recordFile.write(byte2);
  recordFile.write(byte3);
  recordFile.write(byte4);
  byte1 = AudioFormat & 0xff;
  byte2 = (AudioFormat >> 8) & 0xff;
  recordFile.write(byte1);
  recordFile.write(byte2);
  byte1 = numChannels & 0xff;
  byte2 = (numChannels >> 8) & 0xff;
  recordFile.write(byte1);
  recordFile.write(byte2);
  byte1 = sampleRate & 0xff;
  byte2 = (sampleRate >> 8) & 0xff;
  byte3 = (sampleRate >> 16) & 0xff;
  byte4 = (sampleRate >> 24) & 0xff;
  recordFile.write(byte1);
  recordFile.write(byte2);
  recordFile.write(byte3);
  recordFile.write(byte4);
  byte1 = byteRate & 0xff;
  byte2 = (byteRate >> 8) & 0xff;
  byte3 = (byteRate >> 16) & 0xff;
  byte4 = (byteRate >> 24) & 0xff;
  recordFile.write(byte1);
  recordFile.write(byte2);
  recordFile.write(byte3);
  recordFile.write(byte4);
  byte1 = blockAlign & 0xff;
  byte2 = (blockAlign >> 8) & 0xff;
  recordFile.write(byte1);
  recordFile.write(byte2);
  byte1 = bitsPerSample & 0xff;
  byte2 = (bitsPerSample >> 8) & 0xff;
  recordFile.write(byte1);
  recordFile.write(byte2);
  recordFile.write("data");
  byte1 = Subchunk2Size & 0xff;
  byte2 = (Subchunk2Size >> 8) & 0xff;
  byte3 = (Subchunk2Size >> 16) & 0xff;
  byte4 = (Subchunk2Size >> 24) & 0xff;
  recordFile.write(byte1);
  recordFile.write(byte2);
  recordFile.write(byte3);
  recordFile.write(byte4);
  // Serial.println("header written");
  // Serial.print("Subchunk2: ");
  // Serial.println(Subchunk2Size);
}

//-----------------------------------------------------//File transfer //---------------------------------------------------------//
void appendRecord(){
  
  fileQueue.enqueue(String(fileName));
  Serial.print("record appended\n\r");
}

void appendEnv(String FileName){
  fileQueue.enqueue(FileName);
}

void ftptransfer(){ 
  id_ftptransfer = threads.id();

  threads.delay((RC1.RecordDuration.toInt()+10)*1000);
  while (1)
  {  
  if(!fileQueue.isempty()){
    Serial.print("\n\r");
    String r;
    String uploadFile = fileQueue.dequeue();
    int str_len = uploadFile.length()+1;
    char upFile[str_len];
    uploadFile.toCharArray(upFile,str_len);

    File file;
    printtime();
    Serial.print(uploadFile);
    Serial.print("\n\r");
    Serial.print("AT+QFTPSTAT\n\r");
    Serial8.print("AT+QFTPSTAT\r\n");
    while (!Serial8.available())
    { }
    r = Serial8.readString();
    Serial.print(r);

    threads.delay(0);

    Serial.printf("AT+QFTPPUT=\"/%s\", \"COM:\",0\n\r",uploadFile.c_str());
    Serial8.printf("AT+QFTPPUT=\"%s/record/%s\", \"COM:\",0\r\n",RC1.DeviceID.c_str(),uploadFile.c_str());
    while (!Serial8.available())
    { }
    r = Serial8.readString();
    Serial.print(r);

    file = SD.open(uploadFile.c_str(),FILE_READ);
    Serial.print("File Open\n\r");

    Serial.print("Writing File\n\r");

    while (file.available())
    {
      //Serial.print("Writing File\n\r");
      Serial8.write(file.read());
      threads.delay(0);
    }
    Serial.print("Writen File\n\r");
    threads.delay(1000);
    Serial.print("+++");
    Serial8.print("+++");
    while (!Serial8.available())
    { }
    r = Serial8.readString();
    Serial.print(r);
    Serial.print("Writen File\n\r");
    threads.delay(1000);
  }
  else{
    Serial.print("No File\n\r");
    threads.delay(1000);
  }
  }
}
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

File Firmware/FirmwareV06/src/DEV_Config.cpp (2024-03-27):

#include "DEV_Config.h"

SoftwareSerial mySerial(34, 35); // RX, TX

/******************************************************************************
function: 
  Uart receiving and sending
******************************************************************************/
UBYTE DEV_Uart_ReceiveByte()
{
  while(1){
    if(mySerial.available()){
      return  mySerial.read();
    }
  }
}

void DEV_Uart_SendByte(char data)
{
  mySerial.write(data);
}

void DEV_Uart_SendString(char *data)
{
  UWORD i;
  for(i=0; data[i] != '\0'; i++){
    mySerial.write(data[i]);
  }
}

void DEV_Uart_ReceiveString(char *data, UWORD Num)
{  
  UWORD i;
  while(1){
    if(mySerial.available()){
        data[i] =  mySerial.read();
        i++;
        //Serial.print(data[i]);
        if(i >= Num){
            break;
          }
      }
   }

  data[Num-1] = '\0';
}

void DEV_Set_GPIOMode(UWORD Pin, UWORD mode)
{

  if(mode == 1){
    pinMode(Pin, INPUT);
  }
  else if(mode == 0){
    pinMode(Pin, OUTPUT);
  }
}


void DEV_Set_Baudrate(UDOUBLE Baudrate)
{
  mySerial.begin(Baudrate);
}

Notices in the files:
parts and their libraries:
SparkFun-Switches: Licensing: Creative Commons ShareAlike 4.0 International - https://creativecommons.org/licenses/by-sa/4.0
